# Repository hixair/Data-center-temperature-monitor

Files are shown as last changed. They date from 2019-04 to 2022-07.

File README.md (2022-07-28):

# A Data Center Temperature Monitor
A temperature monitor based on and ESP32 and DS18B20 sensors, that can be mounted in a server rack.

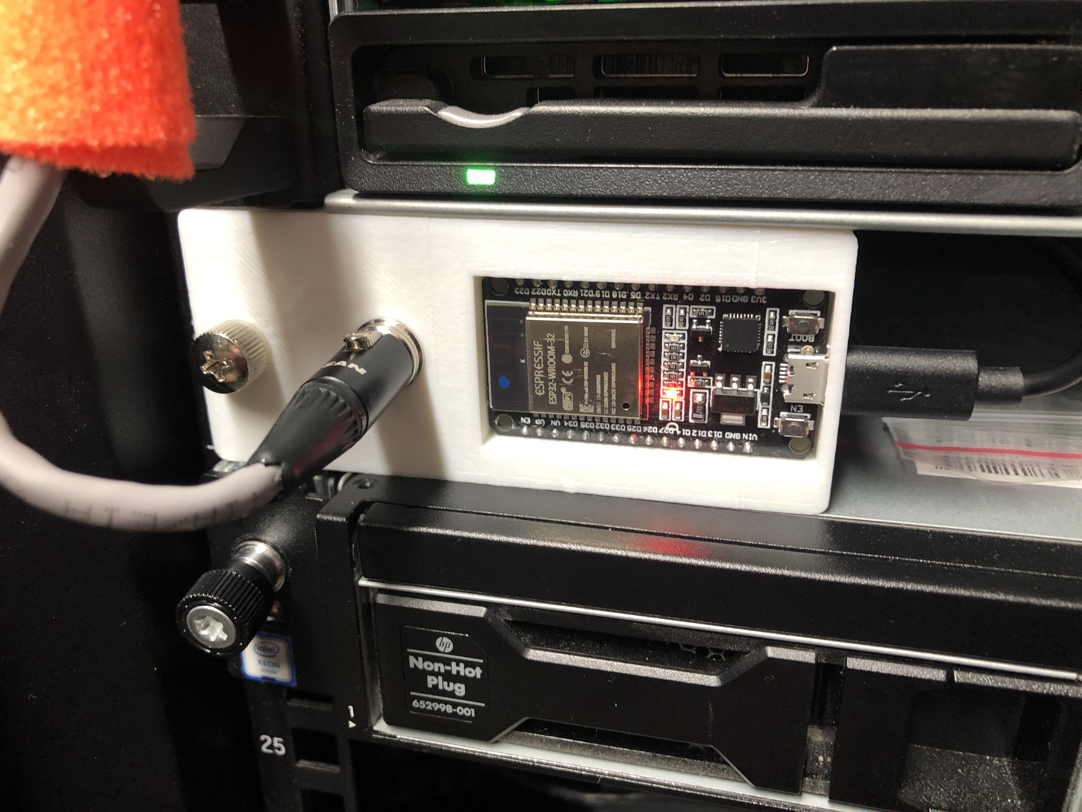
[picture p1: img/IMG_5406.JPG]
Temperaturemonitor temperature monitor


## The project

I know, yet another temperature monitor ...
This is my first complete project that involves CAD design, 3D printing, electronics prototyping, C code (I am not a developer ;) and webhooks.

Goals of this project : 
- Getting temperatures from the 3 sensors (AC, back of the server racks and ambient) 
- Log the temperatures and build a graph to monitor trends overtime.
- Send live alerts when a temperature level is reached.

## Connecting the sensors to the controller

I initially prototyped the temperature monitor using the typical breadboard :

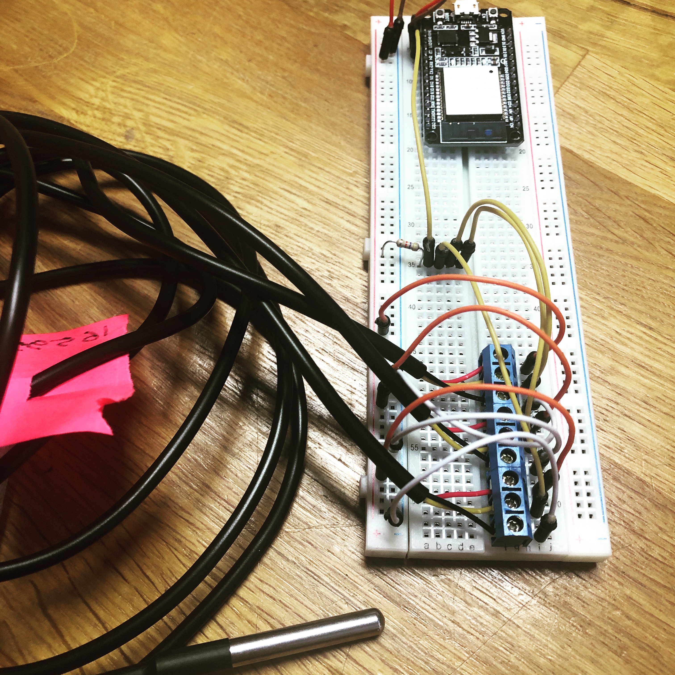
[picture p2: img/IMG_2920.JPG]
breadboard


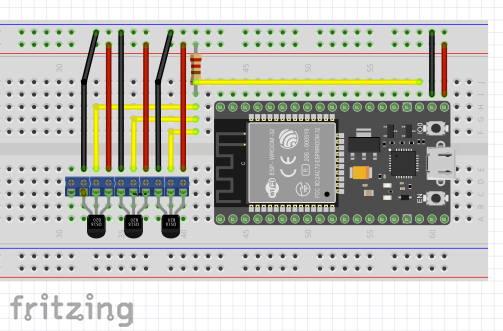
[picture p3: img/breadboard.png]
breadboard2


I spliced the sensors to Cat5 network cables and ended cables with mini-XLR connectors (these are pretty cool as they have 3 pins and a locking lever). 
The DS18B20 is accessed through a one wire bus, it means that they are all connected to the same wire and you can add many sensors as long as you power them accordingly.

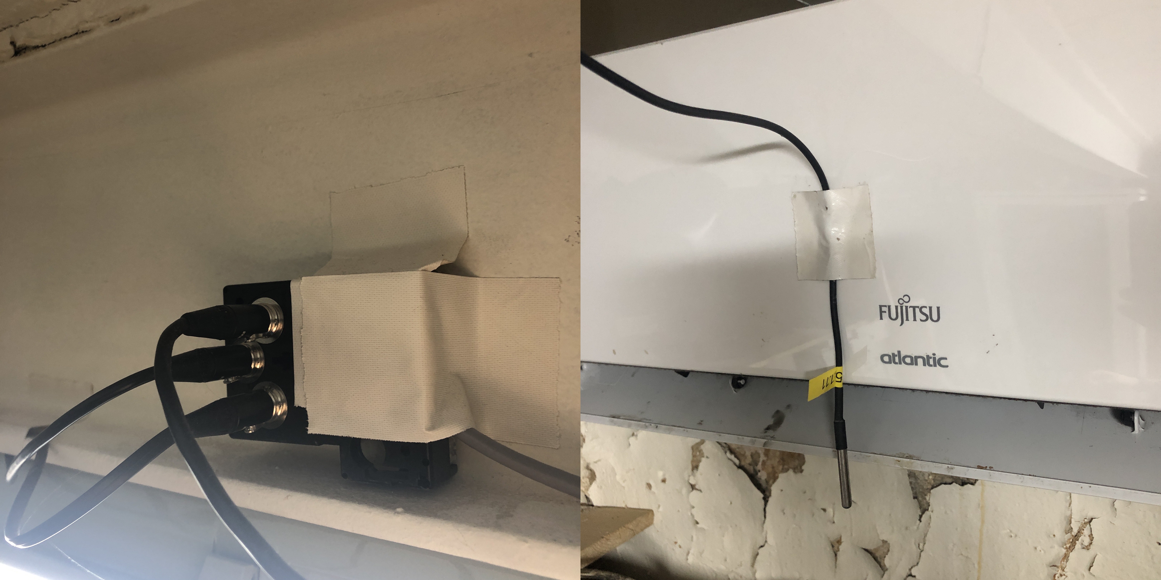
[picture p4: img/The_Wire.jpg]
The Wire

*I used a old epson ribbon printer cartridge as a case for 3 female plugs. These are connected to the main wire going to the controller. I could easily go with many other sensors plugging in one of these plugs ...*

Each sensor has an address and you can use the code from the `DS18B20 Sensor Address.c` sketch to figure them out. Upload the sketch to the esp32, plug one of the sensor, switch on, read the value in the serial monitor, switch off, plug another sensor, ...

Label your sensors in case you want to move them or reuse them.

## The Case

The first interation of the case revealed that wifi does not do well when the antenna of the controller is placed between 2 server blades (and the access to the usb plug was really bad) :

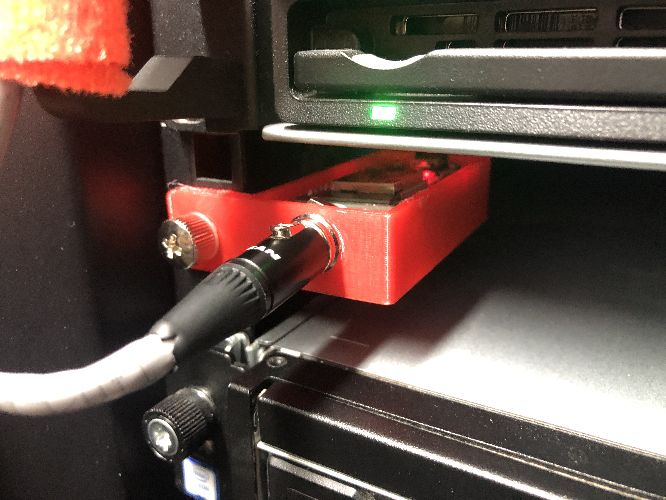
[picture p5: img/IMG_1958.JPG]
first case


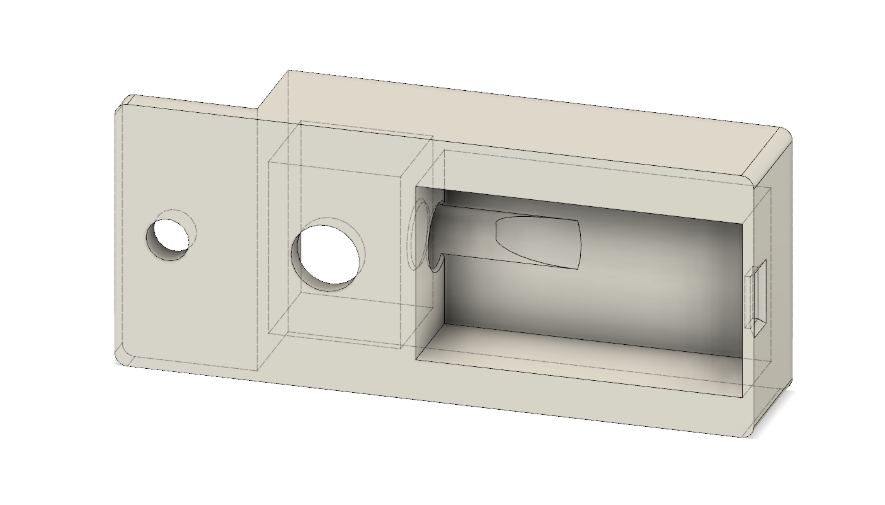
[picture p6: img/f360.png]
f360


I messed up some dimentions and had to go back to f360 to fix the problems :

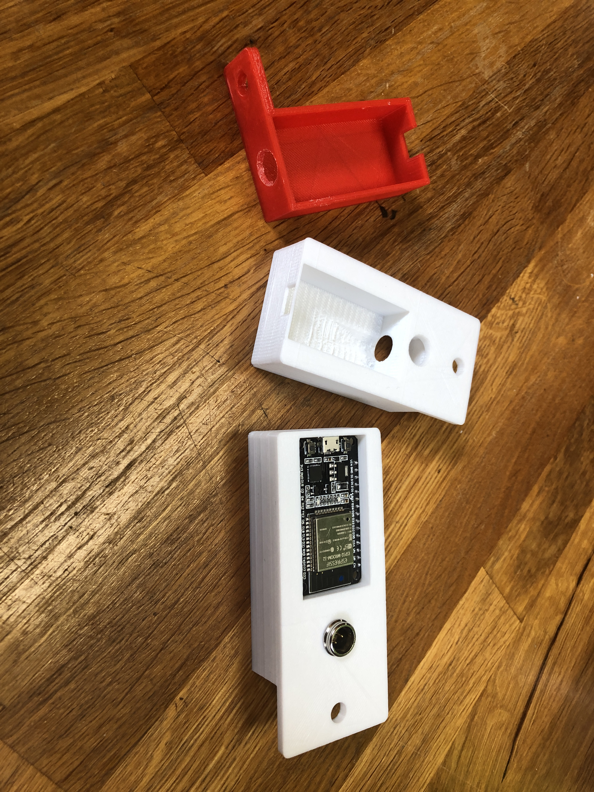
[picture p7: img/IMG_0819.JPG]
3D printing is awesome

*(3D printing is awesome)*

Final case :

Cold Case

Updated case for the Olimex ESP32-POE :

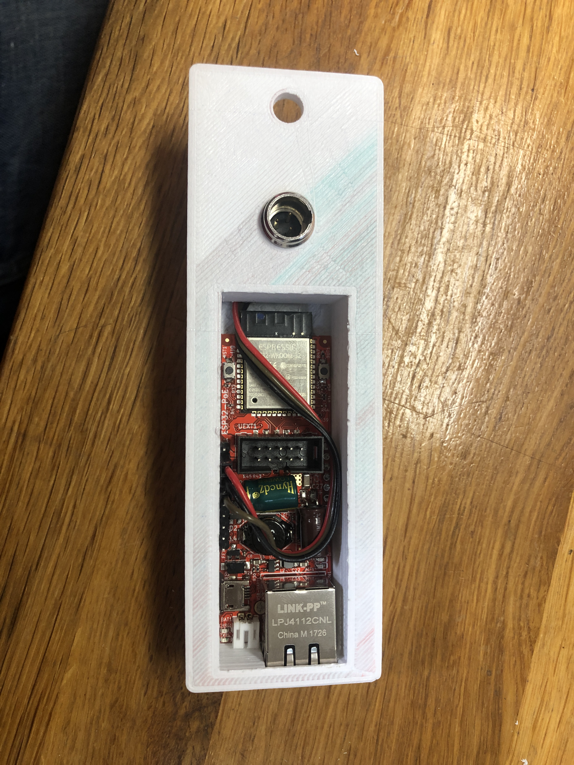
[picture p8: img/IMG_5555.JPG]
ESP32-POE-Case


## The Code

The code is pretty straightforward, I used a lot of existing bits and stiched everything together. It probably lacks some error checkings while posting. 
The SSL part of the webhook gave me some headhaches (Thanks you Alex for your help !).
Make sure you include all the required librairies !

## Posting the temperature values

We are using Inegromat for several other projects and it is really cool to use.
Values are read by the controller and then posted to Integromat via a WebHook. Integromat then stores the values in a Google sheet (we may move this to a logstash/kibana).

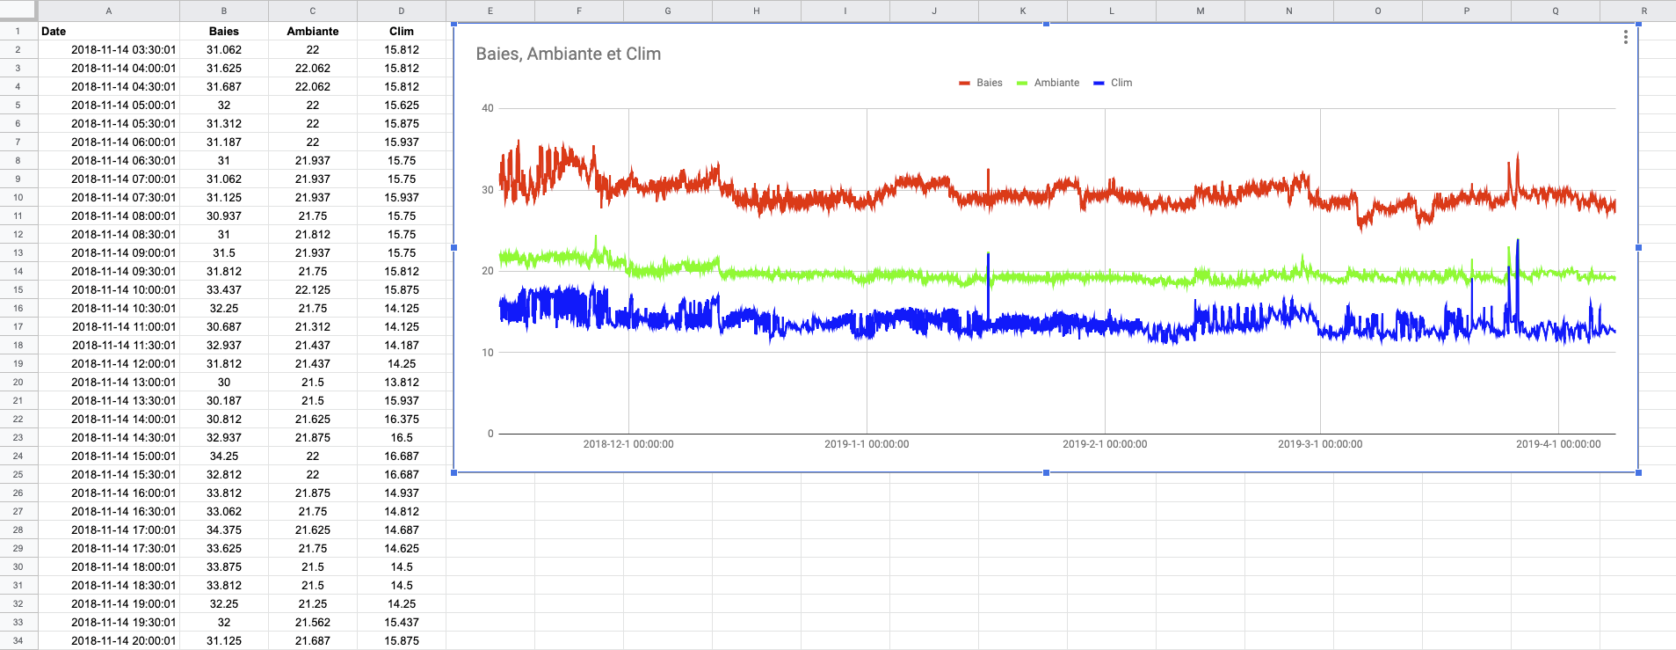
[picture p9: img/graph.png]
graph


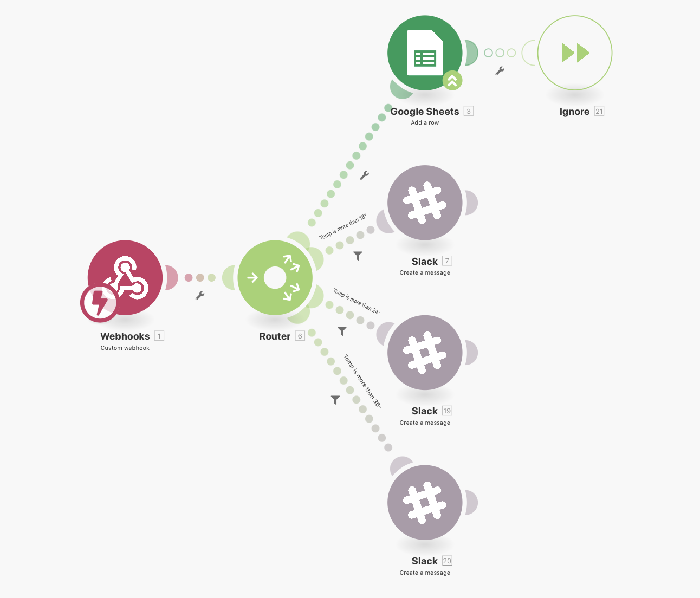
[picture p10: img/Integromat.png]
Integromat


If one of tha values goes beyond a set theshold, an alert is send to a Slack Channel.

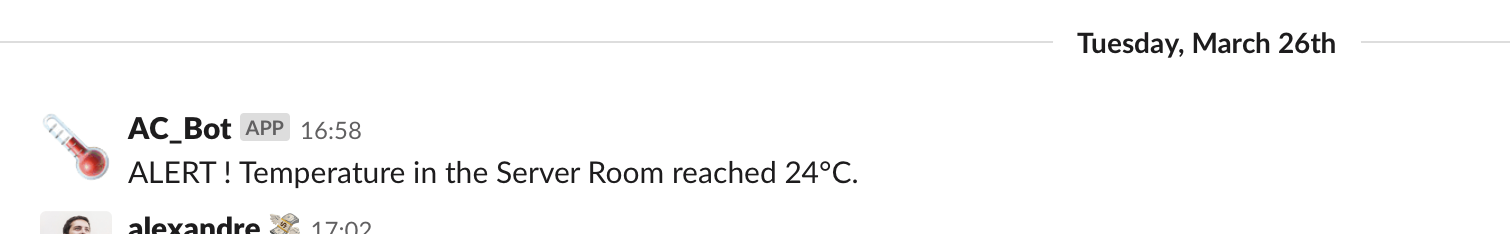
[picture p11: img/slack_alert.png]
slack_alert


## Final considerations
Wifi ... Well ... is ... Wifi ... Connexion was not reliable and the project was updated to work on an Olimex ESP32-POE https://github.com/OLIMEX/ESP32-POE. 
I uploaded the new code and case file.

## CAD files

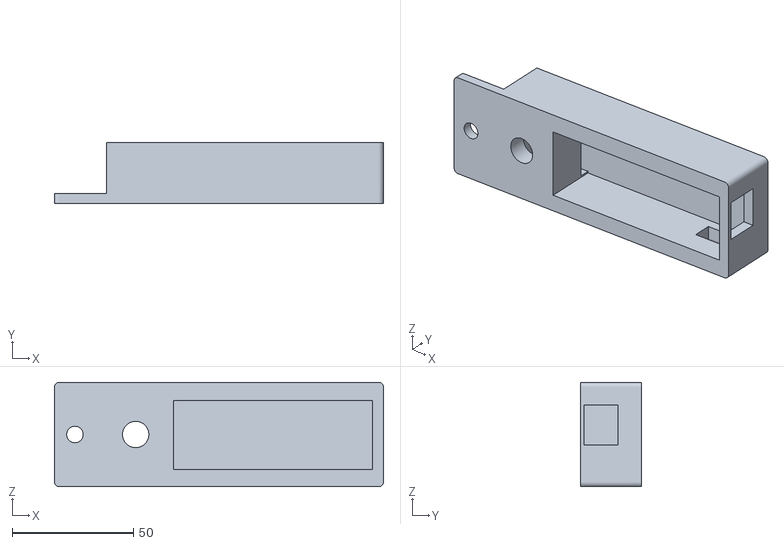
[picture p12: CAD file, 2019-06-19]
1U_rack_mount_for_Olimex-ESP32-POE.stl
135.4 x 24.9 x 43.0

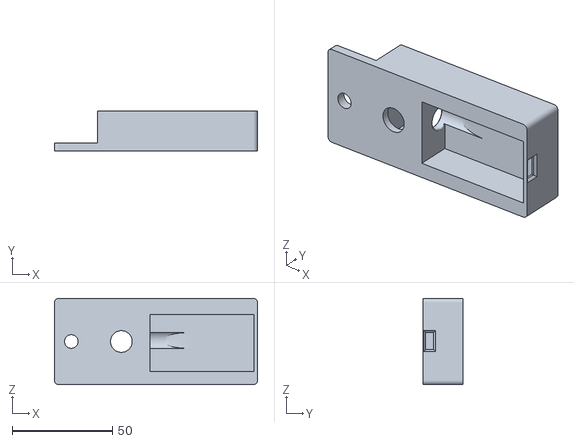
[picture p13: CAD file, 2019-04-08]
1U-case.stl
101.4 x 20.1 x 43.0

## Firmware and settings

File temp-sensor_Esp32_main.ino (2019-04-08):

#include <OneWire.h>
#include <DallasTemperature.h>
#include <WiFi.h>
#include <HTTPClient.h>
#include <time.h>

// WiFi settings
#define WIFI_SSID "YOURSSID"
#define WIFI_PASSWORD "YOURSSIRDPASSWORD"

// Delay between temperature checks (in minutes)
#define CHECK_INTERVAL 15

// Setup a oneWire instance to communicate with a OneWire device on GPIO 15
OneWire oneWire(15);

// Pass our oneWire reference to Dallas Temperature sensor
DallasTemperature sensors(&oneWire);

DeviceAddress sensor_rack    = { 0x28, 0xF0, 0x66, 0xAE, 0x08, 0x00, 0x00, 0x78 };
DeviceAddress sensor_ac      = { 0x28, 0xFF, 0x9B, 0x1A, 0xA2, 0x16, 0x03, 0xB1 };
DeviceAddress sensor_ambient = { 0x28, 0xFF, 0x01, 0xE4, 0xA2, 0x16, 0x03, 0xDF };

const char *ntpServer = "pool.ntp.org";

static const char integromat_root_ca[] PROGMEM = R"EOF(
-----BEGIN CERTIFICATE-----
MIIF2DCCA8CgAwIBAgIQTKr5yttjb+Af907YWwOGnTANBgkqhkiG9w0BAQwFADCB
hTELMAkGA1UEBhMCR0IxGzAZBgNVBAgTEkdyZWF0ZXIgTWFuY2hlc3RlcjEQMA4G
A1UEBxMHU2FsZm9yZDEaMBgGA1UEChMRQ09NT0RPIENBIExpbWl0ZWQxKzApBgNV
BAMTIkNPTU9ETyBSU0EgQ2VydGlmaWNhdGlvbiBBdXRob3JpdHkwHhcNMTAwMTE5
MDAwMDAwWhcNMzgwMTE4MjM1OTU5WjCBhTELMAkGA1UEBhMCR0IxGzAZBgNVBAgT
EkdyZWF0ZXIgTWFuY2hlc3RlcjEQMA4GA1UEBxMHU2FsZm9yZDEaMBgGA1UEChMR
Q09NT0RPIENBIExpbWl0ZWQxKzApBgNVBAMTIkNPTU9ETyBSU0EgQ2VydGlmaWNh
dGlvbiBBdXRob3JpdHkwggIiMA0GCSqGSIb3DQEBAQUAA4ICDwAwggIKAoICAQCR
6FSS0gpWsawNJN3Fz0RndJkrN6N9I3AAcbxT38T6KhKPS38QVr2fcHK3YX/JSw8X
pz3jsARh7v8Rl8f0hj4K+j5c+ZPmNHrZFGvnnLOFoIJ6dq9xkNfs/Q36nGz637CC
9BR++b7Epi9Pf5l/tfxnQ3K9DADWietrLNPtj5gcFKt+5eNu/Nio5JIk2kNrYrhV
/erBvGy2i/MOjZrkm2xpmfh4SDBF1a3hDTxFYPwyllEnvGfDyi62a+pGx8cgoLEf
Zd5ICLqkTqnyg0Y3hOvozIFIQ2dOciqbXL1MGyiKXCJ7tKuY2e7gUYPDCUZObT6Z
+pUX2nwzV0E8jVHtC7ZcryxjGt9XyD+86V3Em69FmeKjWiS0uqlWPc9vqv9JWL7w
qP/0uK3pN/u6uPQLOvnoQ0IeidiEyxPx2bvhiWC4jChWrBQdnArncevPDt09qZah
SL0896+1DSJMwBGB7FY79tOi4lu3sgQiUpWAk2nojkxl8ZEDLXB0AuqLZxUpaVIC
u9ffUGpVRr+goyhhf3DQw6KqLCGqR84onAZFdr+CGCe01a60y1Dma/RMhnEw6abf
Fobg2P9A3fvQQoh/ozM6LlweQRGBY84YcWsr7KaKtzFcOmpH4MN5WdYgGq/yapiq
crxXStJLnbsQ/LBMQeXtHT1eKJ2czL+zUdqnR+WEUwIDAQABo0IwQDAdBgNVHQ4E
FgQUu69+Aj36pvE8hI6t7jiY7NkyMtQwDgYDVR0PAQH/BAQDAgEGMA8GA1UdEwEB
/wQFMAMBAf8wDQYJKoZIhvcNAQEMBQADggIBAArx1UaEt65Ru2yyTUEUAJNMnMvl
wFTPoCWOAvn9sKIN9SCYPBMtrFaisNZ+EZLpLrqeLppysb0ZRGxhNaKatBYSaVqM
4dc+pBroLwP0rmEdEBsqpIt6xf4FpuHA1sj+nq6PK7o9mfjYcwlYRm6mnPTXJ9OV
2jeDchzTc+CiR5kDOF3VSXkAKRzH7JsgHAckaVd4sjn8OoSgtZx8jb8uk2Intzna
FxiuvTwJaP+EmzzV1gsD41eeFPfR60/IvYcjt7ZJQ3mFXLrrkguhxuhoqEwWsRqZ
CuhTLJK7oQkYdQxlqHvLI7cawiiFwxv/0Cti76R7CZGYZ4wUAc1oBmpjIXUDgIiK
boHGhfKppC3n9KUkEEeDys30jXlYsQab5xoq2Z0B15R97QNKyvDb6KkBPvVWmcke
jkk9u+UJueBPSZI9FoJAzMxZxuY67RIuaTxslbH9qh17f4a+Hg4yRvv7E491f0yL
S0Zj/gA0QHDBw7mh3aZw4gSzQbzpgJHqZJx64SIDqZxubw5lT2yHh17zbqD5daWb
QOhTsiedSrnAdyGN/4fy3ryM7xfft0kL0fJuMAsaDk527RH89elWsn2/x20Kk4yl
0MC2Hb46TpSi125sC8KKfPog88Tk5c0NqMuRkrF8hey1FGlmDoLnzc7ILaZRfyHB
NVOFBkpdn627G190
-----END CERTIFICATE-----
)EOF";

void setup(void){
  Serial.begin(115200);
  sensors.begin();

  Serial.print("Connecting to ");
  Serial.print(WIFI_SSID);

  WiFi.begin(WIFI_SSID, WIFI_PASSWORD);
  while (WiFi.status() != WL_CONNECTED) {
    delay(500);
    Serial.print(".");
  }

  Serial.println();
  Serial.print("Connected to the WiFi network");
  Serial.print(", IP address: ");
  Serial.println(WiFi.localIP());

  configTime(0, 0, ntpServer);
}

void loop(void){
  Serial.print("Reading temperatures... ");
  sensors.requestTemperatures();
  Serial.println("OK");

  Serial.print("Rack temperature: ");
  Serial.print(sensors.getTempC(sensor_rack));
  Serial.println("°C");

  Serial.print("AC temperature: ");
  Serial.print(sensors.getTempC(sensor_ac));
  Serial.println("°C");

  Serial.print("Ambient temperature: ");
  Serial.print(sensors.getTempC(sensor_ambient));
  Serial.println("°C");

  struct tm timeinfo;
  if (!getLocalTime(&timeinfo)){
    Serial.println("Failed to get time.");
    return;
  }

  char payload[200];
  snprintf(payload, sizeof(payload), "{\"date\":\"%04d-%02d-%02d %02d:%02d:%02d\",\"rack_temp\":%f,\"ac_temp\":%f,\"ambient_temp\":%f}",
           timeinfo.tm_year + 1900, timeinfo.tm_mon + 1, timeinfo.tm_mday, timeinfo.tm_hour, timeinfo.tm_min, timeinfo.tm_sec,
           sensors.getTempC(sensor_rack), sensors.getTempC(sensor_ac), sensors.getTempC(sensor_ambient));

  HTTPClient http;
  http.begin("https://hook.integromat.com/HookID", integromat_root_ca);
  http.addHeader("Content-Type", "application/json");
  http.POST(payload);

  delay(CHECK_INTERVAL * 60 * 1000);
}

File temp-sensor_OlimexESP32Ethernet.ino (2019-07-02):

#define ETH_CLK_MODE    ETH_CLOCK_GPIO17_OUT
#define ETH_PHY_POWER   12

#include <ETH.h>
#include <OneWire.h>
#include <DallasTemperature.h>
#include <WiFi.h>
#include <HTTPClient.h>
#include <Time.h>
#include <TimeLib.h>
#include "ntp.h"

// Delay between temperature checks (in minutes)
#define CHECK_INTERVAL 5

#define NTP_SERVER "pool.ntp.org"
#define NTP_SYNC_INTERVAL 60

// Setup a oneWire instance to communicate with a OneWire device on GPIO 15
OneWire oneWire(0);

// Pass our oneWire reference to Dallas Temperature sensor
DallasTemperature sensors(&oneWire);

DeviceAddress sensor_rack    = { 0x28, 0xF0, 0x66, 0xAE, 0x08, 0x00, 0x00, 0x78 };
DeviceAddress sensor_ac      = { 0x28, 0xFF, 0x9B, 0x1A, 0xA2, 0x16, 0x03, 0xB1 };
DeviceAddress sensor_ambient = { 0x28, 0xFF, 0x01, 0xE4, 0xA2, 0x16, 0x03, 0xDF };

bool eth_connected = false;

static const char integromat_root_ca[] PROGMEM = R"EOF(
-----BEGIN CERTIFICATE-----
MIIF2DCCA8CgAwIBAgIQTKr5yttjb+Af907YWwOGnTANBgkqhkiG9w0BAQwFADCB
hTELMAkGA1UEBhMCR0IxGzAZBgNVBAgTEkdyZWF0ZXIgTWFuY2hlc3RlcjEQMA4G
A1UEBxMHU2FsZm9yZDEaMBgGA1UEChMRQ09NT0RPIENBIExpbWl0ZWQxKzApBgNV
BAMTIkNPTU9ETyBSU0EgQ2VydGlmaWNhdGlvbiBBdXRob3JpdHkwHhcNMTAwMTE5
MDAwMDAwWhcNMzgwMTE4MjM1OTU5WjCBhTELMAkGA1UEBhMCR0IxGzAZBgNVBAgT
EkdyZWF0ZXIgTWFuY2hlc3RlcjEQMA4GA1UEBxMHU2FsZm9yZDEaMBgGA1UEChMR
Q09NT0RPIENBIExpbWl0ZWQxKzApBgNVBAMTIkNPTU9ETyBSU0EgQ2VydGlmaWNh
dGlvbiBBdXRob3JpdHkwggIiMA0GCSqGSIb3DQEBAQUAA4ICDwAwggIKAoICAQCR
6FSS0gpWsawNJN3Fz0RndJkrN6N9I3AAcbxT38T6KhKPS38QVr2fcHK3YX/JSw8X
pz3jsARh7v8Rl8f0hj4K+j5c+ZPmNHrZFGvnnLOFoIJ6dq9xkNfs/Q36nGz637CC
9BR++b7Epi9Pf5l/tfxnQ3K9DADWietrLNPtj5gcFKt+5eNu/Nio5JIk2kNrYrhV
/erBvGy2i/MOjZrkm2xpmfh4SDBF1a3hDTxFYPwyllEnvGfDyi62a+pGx8cgoLEf
Zd5ICLqkTqnyg0Y3hOvozIFIQ2dOciqbXL1MGyiKXCJ7tKuY2e7gUYPDCUZObT6Z
+pUX2nwzV0E8jVHtC7ZcryxjGt9XyD+86V3Em69FmeKjWiS0uqlWPc9vqv9JWL7w
qP/0uK3pN/u6uPQLOvnoQ0IeidiEyxPx2bvhiWC4jChWrBQdnArncevPDt09qZah
SL0896+1DSJMwBGB7FY79tOi4lu3sgQiUpWAk2nojkxl8ZEDLXB0AuqLZxUpaVIC
u9ffUGpVRr+goyhhf3DQw6KqLCGqR84onAZFdr+CGCe01a60y1Dma/RMhnEw6abf
Fobg2P9A3fvQQoh/ozM6LlweQRGBY84YcWsr7KaKtzFcOmpH4MN5WdYgGq/yapiq
crxXStJLnbsQ/LBMQeXtHT1eKJ2czL+zUdqnR+WEUwIDAQABo0IwQDAdBgNVHQ4E
FgQUu69+Aj36pvE8hI6t7jiY7NkyMtQwDgYDVR0PAQH/BAQDAgEGMA8GA1UdEwEB
/wQFMAMBAf8wDQYJKoZIhvcNAQEMBQADggIBAArx1UaEt65Ru2yyTUEUAJNMnMvl
wFTPoCWOAvn9sKIN9SCYPBMtrFaisNZ+EZLpLrqeLppysb0ZRGxhNaKatBYSaVqM
4dc+pBroLwP0rmEdEBsqpIt6xf4FpuHA1sj+nq6PK7o9mfjYcwlYRm6mnPTXJ9OV
2jeDchzTc+CiR5kDOF3VSXkAKRzH7JsgHAckaVd4sjn8OoSgtZx8jb8uk2Intzna
FxiuvTwJaP+EmzzV1gsD41eeFPfR60/IvYcjt7ZJQ3mFXLrrkguhxuhoqEwWsRqZ
CuhTLJK7oQkYdQxlqHvLI7cawiiFwxv/0Cti76R7CZGYZ4wUAc1oBmpjIXUDgIiK
boHGhfKppC3n9KUkEEeDys30jXlYsQab5xoq2Z0B15R97QNKyvDb6KkBPvVWmcke
jkk9u+UJueBPSZI9FoJAzMxZxuY67RIuaTxslbH9qh17f4a+Hg4yRvv7E491f0yL
S0Zj/gA0QHDBw7mh3aZw4gSzQbzpgJHqZJx64SIDqZxubw5lT2yHh17zbqD5daWb
QOhTsiedSrnAdyGN/4fy3ryM7xfft0kL0fJuMAsaDk527RH89elWsn2/x20Kk4yl
0MC2Hb46TpSi125sC8KKfPog88Tk5c0NqMuRkrF8hey1FGlmDoLnzc7ILaZRfyHB
NVOFBkpdn627G190
-----END CERTIFICATE-----
)EOF";

void WiFiEvent(WiFiEvent_t event)
{
  switch (event) {
    case SYSTEM_EVENT_ETH_START:
      Serial.println("ETH Started");
      //set eth hostname here
      ETH.setHostname("esp32-ethernet");
      break;
    case SYSTEM_EVENT_ETH_CONNECTED:
      Serial.println("ETH Connected");
      break;
    case SYSTEM_EVENT_ETH_GOT_IP:
      Serial.print("ETH MAC: ");
      Serial.print(ETH.macAddress());
      Serial.print(", IPv4: ");
      Serial.print(ETH.localIP());
      if (ETH.fullDuplex()) {
        Serial.print(", FULL_DUPLEX");
      }
      Serial.print(", ");
      Serial.print(ETH.linkSpeed());
      Serial.println("Mbps");
      eth_connected = true;
      setupNTP(NTP_SERVER, NTP_SYNC_INTERVAL);
      break;
    case SYSTEM_EVENT_ETH_DISCONNECTED:
      Serial.println("ETH Disconnected");
      eth_connected = false;
      break;
    case SYSTEM_EVENT_ETH_STOP:
      Serial.println("ETH Stopped");
      eth_connected = false;
      break;
    default:
      break;
  }
}




void setup(void){
  Serial.begin(115200);
  Serial.println("Init...");

  sensors.begin();

  WiFi.onEvent(WiFiEvent);
  ETH.begin();

  discoverOneWireDevices();

  Serial.println("Waiting for ethernet...");
}

void loop(void){
  if (!eth_connected) {
    return;
  }

  Serial.print("Reading temperatures... ");
  sensors.requestTemperatures();
  Serial.println("OK");

  Serial.print("Rack temperature: ");
  Serial.print(sensors.getTempC(sensor_rack));
  Serial.println("°C");

  Serial.print("AC temperature: ");
  Serial.print(sensors.getTempC(sensor_ac));
  Serial.println("°C");

  Serial.print("Ambient temperature: ");
  Serial.print(sensors.getTempC(sensor_ambient));
  Serial.println("°C");

  char payload[200];
  snprintf(payload, sizeof(payload), "{\"date\":\"%04d-%02d-%02d %02d:%02d:%02d\",\"rack_temp\":%f,\"ac_temp\":%f,\"ambient_temp\":%f}",
           year(), month(), day(), hour(), minute(), second(),
           sensors.getTempC(sensor_rack), sensors.getTempC(sensor_ac), sensors.getTempC(sensor_ambient));

  HTTPClient http;
  http.begin("https://hook.integromat.com/0hm2cmrmy4fus0t2tc8lxnxegu2f5yq5", integromat_root_ca);
  http.addHeader("Content-Type", "application/json");
  http.POST(payload);

  delay(CHECK_INTERVAL * 60 * 1000);
}

void discoverOneWireDevices(void) {
  byte i;
  byte present = 0;
  byte data[12];
  byte addr[8];

  Serial.print("Looking for 1-Wire devices...\n\r");
  while(oneWire.search(addr)) {
    Serial.print("\n\rFound \'1-Wire\' device with address:\n\r");
    for( i = 0; i < 8; i++) {
      Serial.print("0x");
      if (addr[i] < 16) {
        Serial.print('0');
      }
      Serial.print(addr[i], HEX);
      if (i < 7) {
        Serial.print(", ");
      }
    }
    if ( OneWire::crc8( addr, 7) != addr[7]) {
        Serial.print("CRC is not valid!\n");
        return;
    }
  }
  Serial.print("\n\r\n\rThat's it.\r\n");
  oneWire.reset_search();
  return;
}

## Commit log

2019-04-08 Create DS18B20 Sensor Address
2019-04-08 Rename DS18B20 Sensor Address to DS18B20 Sensor Address.c
2019-06-04 Add files via upload
    added code for Olimex ESP 32 dev board with ethernet port.
2019-07-02 Update Olimex ESP32 code
